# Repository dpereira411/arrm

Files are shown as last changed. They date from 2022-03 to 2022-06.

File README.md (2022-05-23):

# Active Real Ring Modulator

This is a Kosmo format synth module based on Ken Stone's CGS [https://sdiy.info/wiki/CGS_active_real_ring_modulator](Active Real Ring Modulator). 

Main difference with Stone's original are:

* The instrument preamplifier was omitted
* Transformer footprints are for the TY-141P instead of the less available MO222
* Final stage input resistor is decreased to 10k, output resistor is increased to 1k, and a 100k pulldown is added on the output.

## Current draw
11.5 mA +12 V, 11.5 mA -12 V

## Photos

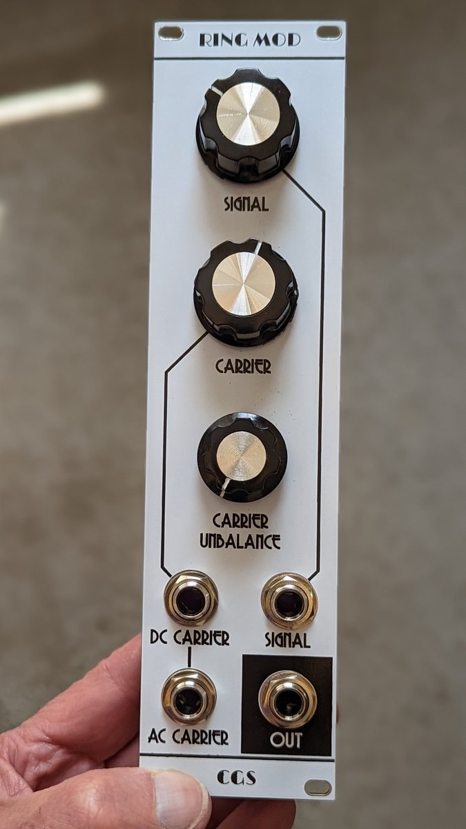
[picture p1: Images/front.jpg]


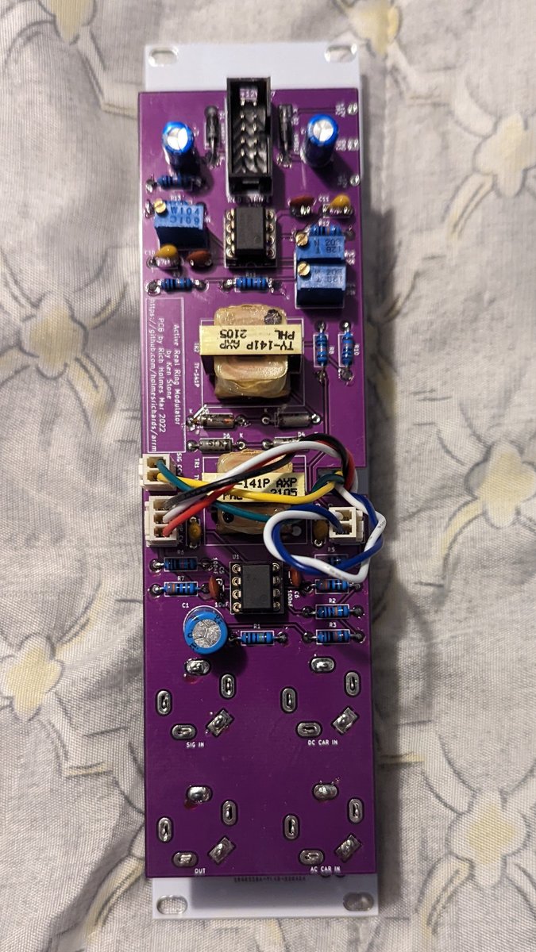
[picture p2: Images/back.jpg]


## Documentation

* [Schematic](Docs/arrm.pdf)
* PCB layout: [front](Docs/arrm_layout_front.pdf), [back](Docs/arrm_layout_back.pdf)
* [BOM](Docs/arrm_bom.md)
* [Build notes](Docs/build.md)
* [Blog post](https://analogoutputblog.wordpress.com/2022/05/05/cgs-ken-stone-active-real-ring-modulator/)

## GitHub repository

* [https://github.com/holmesrichards/arrm](https://github.com/holmesrichards/arrm)

## Submodules

This repo uses submodules aoKicad and Kosmo_panel, which provide needed libaries for KiCad. To clone:

```
git clone git@github.com:holmesrichards/arrm.git
git submodule init
git submodule update
```

Alternatively do

```
git clone --recurse-submodules git@github.com:holmesrichards/arrm.git
```

Or if you download the repository as a zip file, you must also click on the "aoKicad" and "Kosmo\_panel" links on the GitHub page (they'll have "@ something" after them) and download them as separate zip files which you can unzip into this repo's aoKicad and Kosmo\_panel directories.

If desired, copy the files from aoKicad and Kosmo\_panel to wherever you prefer (your KiCad user library directory, for instance, if you have one). Then in KiCad, go into Edit Symbols and add symbol libraries 

```
aoKicad/ao_symbols
Kosmo_panel/Kosmo
```
and go into Edit Footprints and add footprint libraries 
```
aoKicad/ao_tht
Kosmo_panel/Kosmo_panel.
```

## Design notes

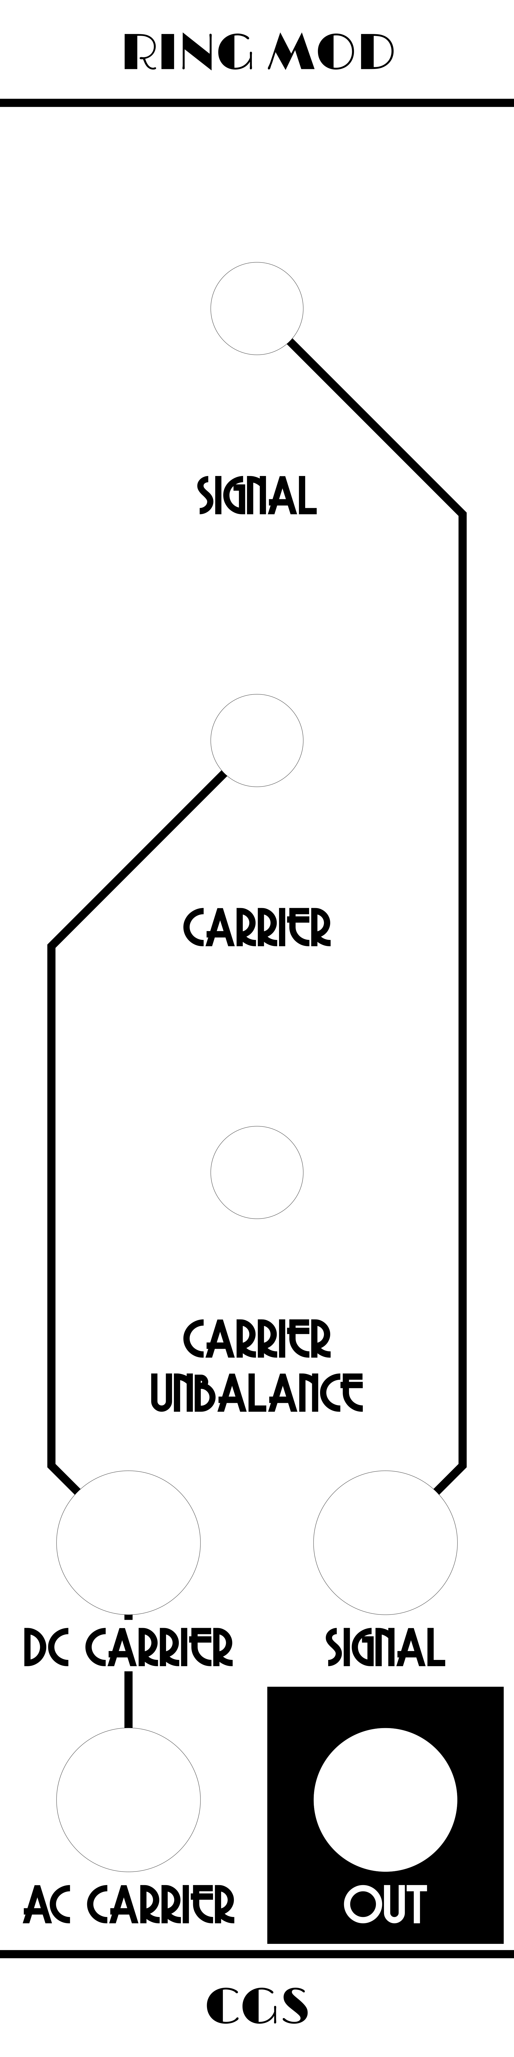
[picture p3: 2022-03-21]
Images/arrm_panel_art.png

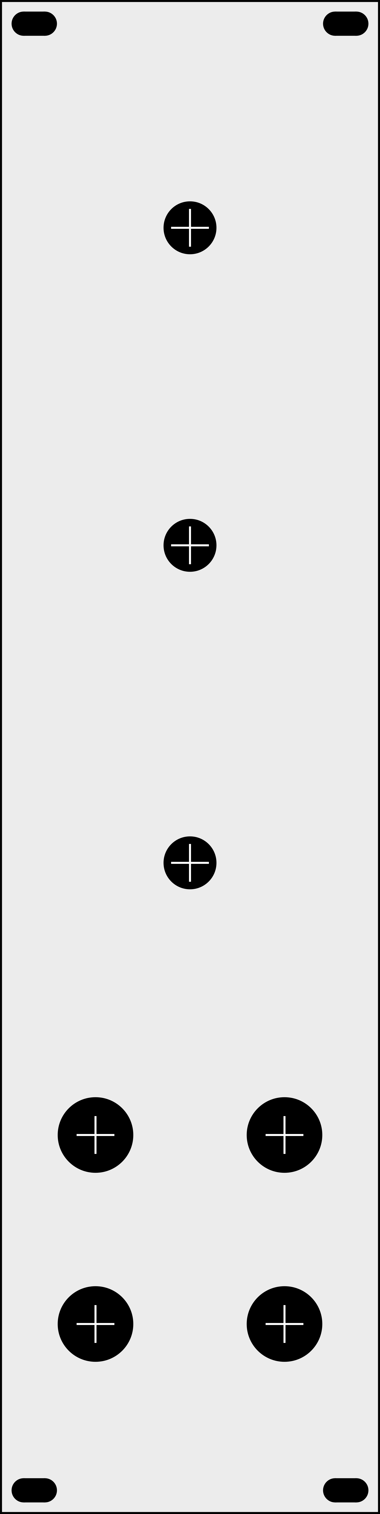
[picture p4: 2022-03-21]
Images/arrm_panel_holes.png

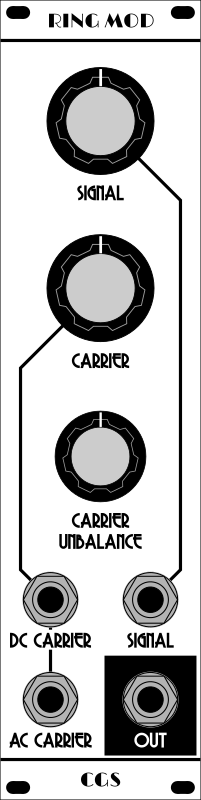
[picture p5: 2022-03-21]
Images/arrm_panel.png

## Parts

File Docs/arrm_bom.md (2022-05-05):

# arrm.kicad_sch BOM

Thu 05 May 2022 06:47:17 PM EDT

Generated from schematic by Eeschema 6.0.4-6f826c9f35~116~ubuntu20.04.1

**Component Count:** 52

| Refs | Qty | Component | Description | Vendor | SKU |
| ----- | --- | ---- | --- | ---- | ---- |
| C1 | 1 | 10uF | Non polarized electrolytic capacitor, pitch 3.5 mm | Tayda | A-4216 |
| C2, C7, C10, C11 | 4 | 47pF | Ceramic capacitor, pitch 5 mm | Tayda |  |
| C3, C4 | 2 | 10uF | Electrolytic capacitor, pitch 2.5 mm | Tayda | A-4349 |
| C5, C6, C8, C9 | 4 | 100nF | Ceramic capacitor, pitch 2.5 mm | Tayda | A-553 |
| D1, D2 | 2 | 1N5817 | Schottky Barrier Rectifier Diode, DO-41 | Tayda | A-159 |
| D3, D4, D5, D6 | 4 | 1N695 | Germanium diode, DO-35 |  |  |
| J1 | 1 | 3_pin_Molex_header | KK254 Molex header | Tayda | A-805 |
| J2, J3 | 2 | 2_pin_Molex_header | KK254 Molex header | Tayda | A-804 |
| J4 | 1 | 3_pin_Molex_connector | KK254 Molex connector | Tayda | A-827 |
| J5, J6 | 2 | 2_pin_Molex_connector | KK254 Molex connector | Tayda | A-826 |
| J7 | 1 | Synth_power_2x5 | Pin header 2.54 mm 2x5 | Tayda | A-2939 |
| J8, J9, J10, J11 | 4 | AudioJack2 | 1/4" audio jack, vertical | Tayda | A-1121 |
| R1 | 1 | 1M | Resistor, 1/4 watt metal film | Tayda |  |
| R2, R3, R6, R8, R9, R10, R12, R14 | 8 | 100k | Resistor, 1/4 watt metal film | Tayda |  |
| R4 | 1 | 330k | Resistor, 1/4 watt metal film | Tayda |  |
| R5, R7 | 2 | 330R | Resistor, 1/4 watt metal film | Tayda |  |
| R11 | 1 | 10k | Resistor, 1/4 watt metal film | Tayda |  |
| R13 | 1 | 1k | Resistor, 1/4 watt metal film | Tayda |  |
| RV1, RV2, RV3 | 3 | 100k | Linear potentiometer, panel mount | Tayda | A-1984 |
| RV4, RV5 | 2 | 20k | Trim-potentiometer | Tayda | A-592 |
| RV6 | 1 | 100k | Trim-potentiometer | Tayda | A-587 |
| TR1, TR2 | 2 | TY-141P | 0.3-300MHz 1:1 RF Transformer, Unbalanced to Balanced Center Tap at Primary/Secondary, CD542 |  |  |
| U1 | 1 | NE5532 | Dual Low-Noise Operational Amplifiers, DIP-8/SOIC-8 | Tayda | A-031 |
| U2 | 1 | TL072 | Dual operational amplifier, DIP-8 | Tayda | A-037 |
| | 2 | | 8 pin DIP socket | Tayda | A-001 |

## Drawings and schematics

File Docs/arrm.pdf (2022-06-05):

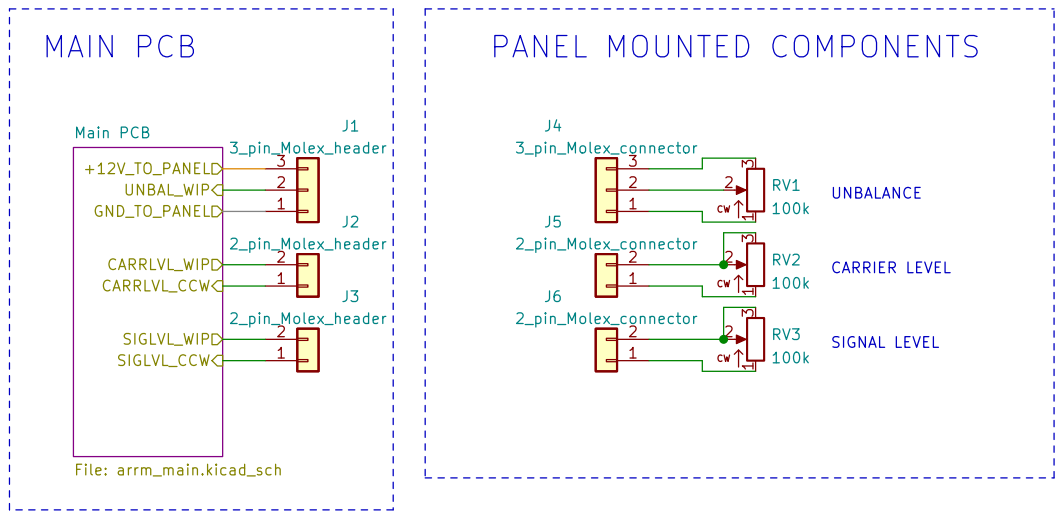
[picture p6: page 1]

SIGNAL LEVEL PANEL MOUNTED COMPONENTS

Circuit design by Ken Stone. SIGLVL_CCW

To the extent possible under law, Richard Holmes has waived all copyright and related
or neighboring rights to this work. Published from United States.
File: arrm.kicad_sch Sheet: / Rich Holmes / Analog Output

Id: 1/2 Title: Active Real Ring Modulator

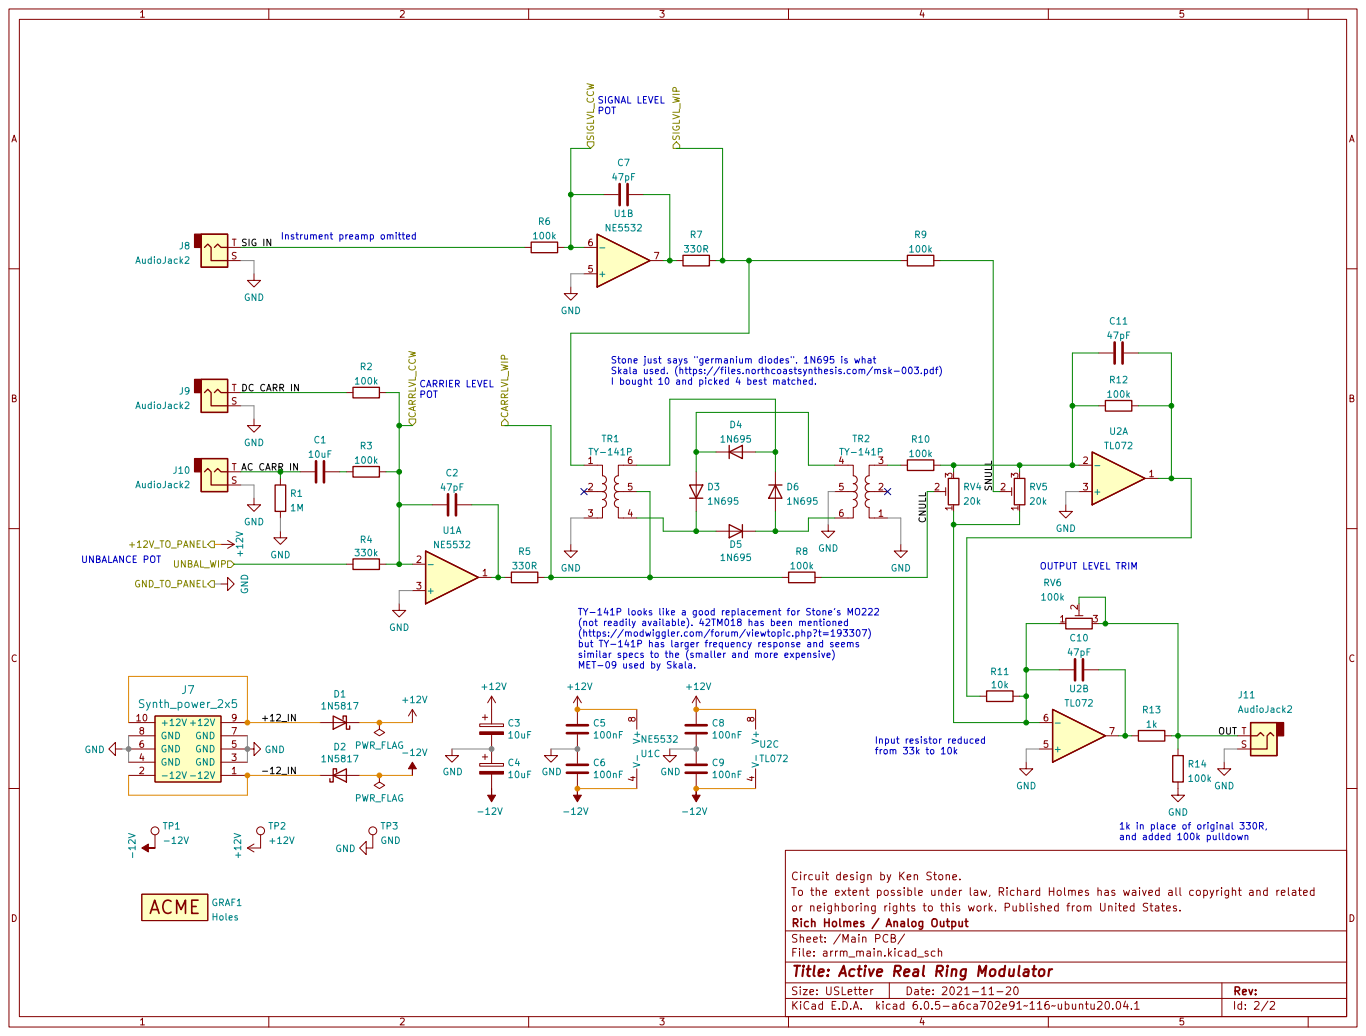
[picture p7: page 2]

I bought 10 and picked 4 best matched. SIGNAL LEVEL POT

Instrument preamp omitted UNBALANCE POT

Stone just says "germanium diodes". 1N695 is what
Skala used. (https://files.northcoastsynthesis.com/msk-003.pdf)

MET-09 used by Skala. CARRIER LEVEL POT

and added 100k pulldown OUTPUT LEVEL TRIM

from 33k to 10k TY-141P looks like a good replacement for Stone's MO222
(not readily available). 42TM018 has been mentioned
(https://modwiggler.com/forum/viewtopic.php?t=193307)
but TY-141P has larger frequency response and seems
similar specs to the (smaller and more expensive)

1k in place of original 330R,

Circuit design by Ken Stone.
To the extent possible under law, Richard Holmes has waived all copyright and related
or neighboring rights to this work. Published from United States.
File: arrm_main.kicad_sch Sheet: /Main PCB/ Rich Holmes / Analog Output

Id: 2/2 Title: Active Real Ring Modulator

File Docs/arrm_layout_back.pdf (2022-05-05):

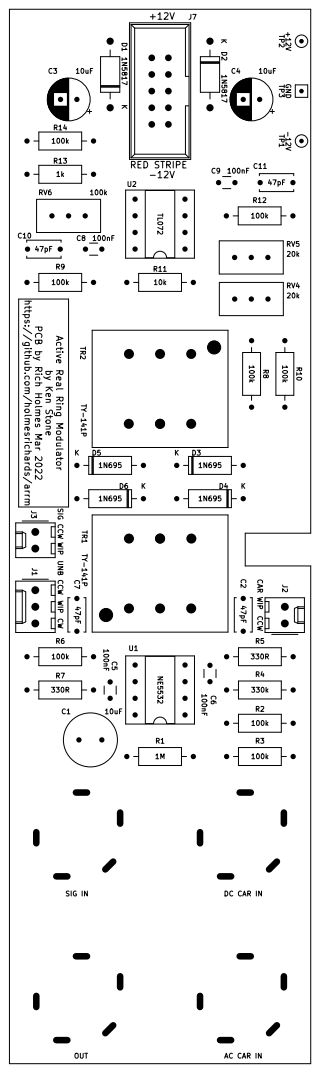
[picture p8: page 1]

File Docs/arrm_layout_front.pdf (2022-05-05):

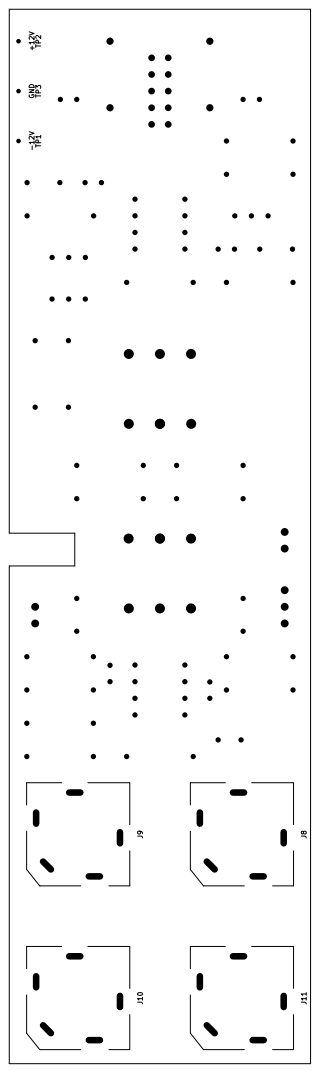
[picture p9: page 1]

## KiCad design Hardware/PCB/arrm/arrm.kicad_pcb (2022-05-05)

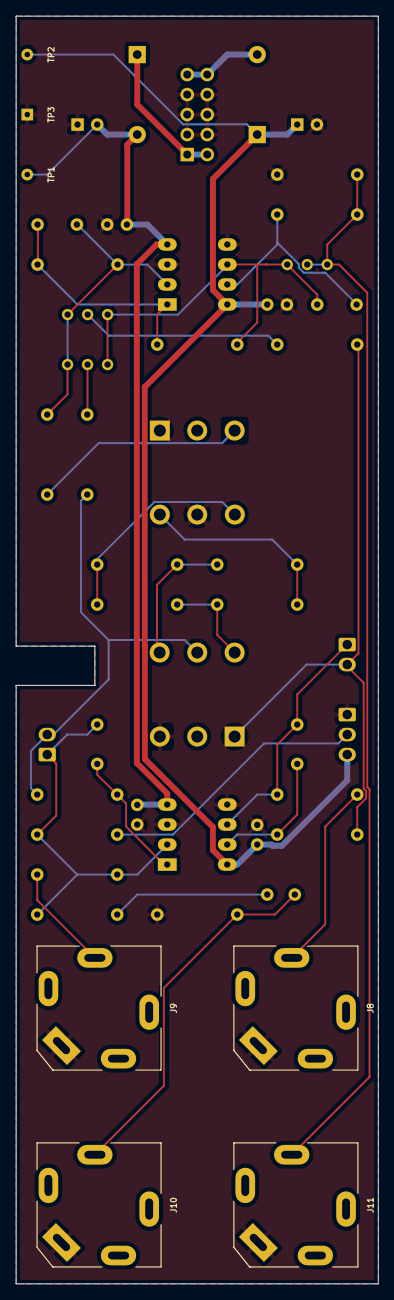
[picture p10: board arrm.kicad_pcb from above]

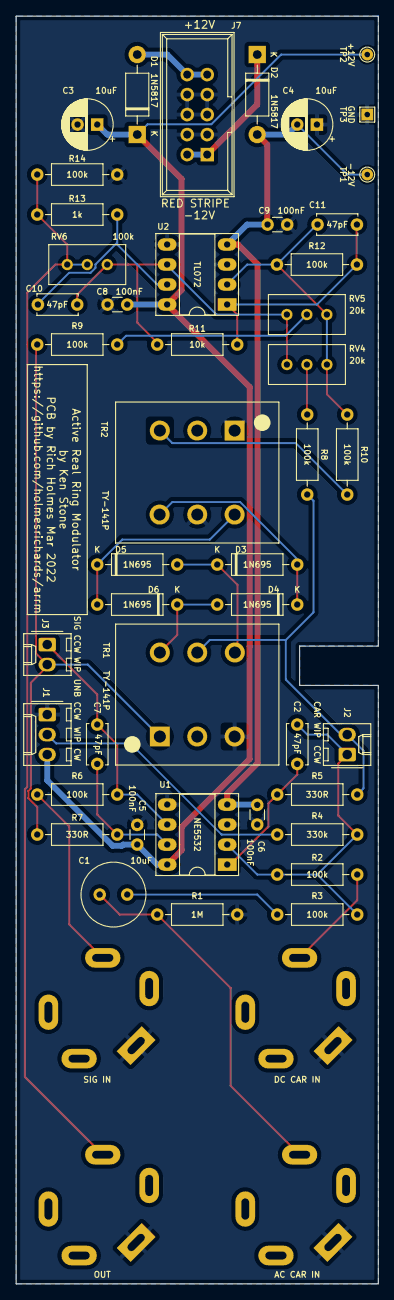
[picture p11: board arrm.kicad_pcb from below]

Board: 2 copper layers, 46.0 x 161.0 mm, 50 parts (45 on the bottom side), 28 nets.

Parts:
C1: 10uF; C_Radial_D8.0mm_H11.5mm_P3.50mm
C2, C7, C10, C11: 47pF; C_Disc_D5.0mm_W2.5mm_P5.00mm
C3, C4: 10uF; CP_Radial_D6.3mm_P2.50mm
C5, C6, C8, C9: 100nF; C_Disc_D3.0mm_W1.6mm_P2.50mm
D1, D2: 1N5817; D_DO-41_SOD81_P10.16mm_Horizontal
D3, D4, D5, D6: 1N695; D_DO-7_P10.16mm_Horizontal
GRAF1: Holes; ringmod_panel_2_holes
J1: 3_pin_Molex_header; Molex_KK-254_AE-6410-03A_1x03_P2.54mm_Vertical
J2, J3: 2_pin_Molex_header; Molex_KK-254_AE-6410-02A_1x02_P2.54mm_Vertical
J7: Synth_power_2x5; Power_Header
J8, J9, J10, J11: AudioJack2; Jack_6.35mm_PJ_629HAN_slots
R1: 1M; R_Axial_DIN0207_L6.3mm_D2.5mm_P10.16mm_Horizontal
R2, R3, R6, R8, R9, R10, R12, R14: 100k; R_Axial_DIN0207_L6.3mm_D2.5mm_P10.16mm_Horizontal
R4: 330k; R_Axial_DIN0207_L6.3mm_D2.5mm_P10.16mm_Horizontal
R5, R7: 330R; R_Axial_DIN0207_L6.3mm_D2.5mm_P10.16mm_Horizontal
R11: 10k; R_Axial_DIN0207_L6.3mm_D2.5mm_P10.16mm_Horizontal
R13: 1k; R_Axial_DIN0207_L6.3mm_D2.5mm_P10.16mm_Horizontal
RV4, RV5: 20k; Potentiometer_Bourns_3296W_Vertical_standard
RV6: 100k; Potentiometer_Bourns_3296W_Vertical_standard
TP1: -12V; TestPoint_THTPad_D1.5mm_Drill0.7mm
TP2: +12V; TestPoint_THTPad_D1.5mm_Drill0.7mm
TP3: GND; TestPoint_THTPad_1.5x1.5mm_Drill0.7mm
TR1, TR2: TY-141P; Transformer_TY-141P
U1: NE5532; DIP-8_W7.62mm_Socket_LongPads
U2: TL072; DIP-8_W7.62mm_Socket_LongPads

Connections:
+12V: C3.1, C5.1, C8.1, D1.1 (K), J1.3, TP2.1, U1.8 (V+), U2.8 (V+)
-12V: C4.2, C6.2, C9.2, D2.2 (A), TP1.1, U1.4 (V-), U2.4 (V-)
/Main PCB/+12_IN: D1.2 (A), J7.9 (+12V), J7.10 (+12V)
/Main PCB/-12_IN: D2.1 (K), J7.1 (-12V), J7.2 (-12V)
/Main PCB/AC CARR IN: C1.2, J10.T, R1.1
/Main PCB/CARRLVL_CCW: C2.1, J2.1, R2.2, R3.2, R4.2, U1.2 (-)
/Main PCB/CARRLVL_WIP: J2.2, R5.2, R8.1, TR1.5
/Main PCB/CNULL: R8.2, RV4.2
/Main PCB/DC CARR IN: J9.T, R2.1
/Main PCB/OUT: J11.T, R13.2, R14.2, RV6.2, RV6.3
/Main PCB/SIG IN: J8.T, R6.1
/Main PCB/SIGLVL_CCW: C7.1, J3.1, R6.2, U1.6 (-)
/Main PCB/SIGLVL_WIP: J3.2, R7.2, R9.1, TR1.1
/Main PCB/SNULL: R9.2, RV5.2
/Main PCB/UNBAL_WIP: J1.2, R4.1
GND: C3.2, C4.1, C5.2, C6.1, C8.2, C9.1, J1.1, J7.3 (GND), J7.4 (GND), J7.5 (GND), J7.6 (GND), J7.7 (GND), J7.8 (GND), J8.S, J9.S, J10.S, J11.S, R1.2, R14.1, TP3.1, TR1.3, TR2.1, TR2.5, U1.3 (+), U1.5 (+), U2.3 (+), U2.5 (+)
unnamed: C1.1, R3.1
unnamed: C2.2, R5.1, U1.1
unnamed: C7.2, R7.1, U1.7
unnamed: C10.1, R11.2, RV4.1, RV5.1, RV6.1, U2.6 (-)
unnamed: C10.2, R13.1, U2.7
unnamed: C11.1, R10.2, R12.1, RV4.3, RV5.3, U2.2 (-)
unnamed: C11.2, R11.1, R12.2, U2.1
unnamed: D3.1 (K), D5.2 (A), TR1.4
unnamed: D3.2 (A), D4.1 (K), TR2.4
unnamed: D4.2 (A), D6.1 (K), TR1.6
unnamed: D5.1 (K), D6.2 (A), TR2.6
unnamed: R10.1, TR2.3

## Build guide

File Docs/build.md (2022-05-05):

# Active Real Ring Modulator build notes

## Erratum

On the first PCB run, the transformer footprints are incorrect; mainly the problem is the dots indicating pin 1 are in the wrong place. They should look like this:

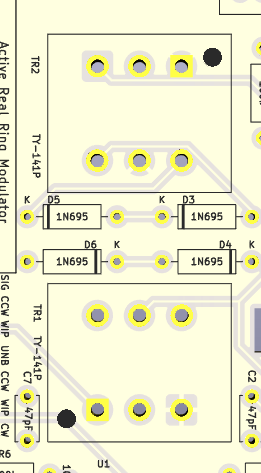
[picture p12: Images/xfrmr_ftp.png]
xfrmr_ftp


Place the dot side of the transformer toward the bottom for TR1 and toward the top for TR2.

R4 has the wrong value shown on the first run PCB silkscreen; it should be 330k, not 330R.

These were corrected after the first run.

# Build

There's nothing exotic about this build. Proceed as usual. Be careful not to overheat the germanium diodes.

Pins 2 and 3 (wiper and clockwise pins as viewed from front) of the Signal and Carrier pots should be connected together, and pins 1 and 2 should be wired to the PCB via Molex connectors or soldered directly. All three pins of the Carrier Unbalance pot should be wired to the PCB. See labels on the PCB indicating which pin goes to which point.

# Diodes

I used the rather traditional 1N695 germanium diodes but you can substitute other diodes. Regular silicon junction diodes like 1N4148 can be used although their high forward voltage means there will be more distortion. Schottky diodes like 1N5817 will have even lower forward voltage than most germanium and a steeper I vs V curve, which may give you results you'd prefer. 

Germanium diodes tend to be more variable, so if your multimeter has a diode setting, use it to select four diodes with closely matched forward voltage.

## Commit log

2021-11-24 Initial version
    [ringmod.kicad_pcb, ringmod.kicad_sch, ringmod_2.kicad_pcb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]
2021-11-25 Update pot symbols
    [ringmod_2.kicad_sch, ringmod_main.kicad_sch]
2021-12-11 .gitignore, fix pot symbols
    [ringmod_2.kicad_sch, ringmod_main.kicad_sch]
2021-12-22 remove inst preamp, redesign panel
    [ringmod_2.kicad_pcb, ringmod_2.kicad_sch, ringmod_main.kicad_sch]
2022-02-01 rm first design; add new holes image
    [ringmod.kicad_pcb, ringmod.kicad_sch, ringmod_2.kicad_pcb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]
2022-03-12 Layout revision
    [ringmod_2.kicad_pcb]
2022-03-19 Rename project; reduce input resistor on output stage
    [arrm.kicad_pcb, arrm.kicad_sch, arrm_main.kicad_sch]
2022-03-21 Rename project, cleanup
    [arrm.kicad_pcb, arrm.kicad_sch, arrm_main.kicad_sch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]
2022-05-03 Final pre fab tweaks, Gerbers
    [arrm-CmtUser.gbr, arrm-CuBottom.gbl, arrm-CuTop.gtl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]
2022-05-03 Fix footprint path; fix transformer footprint
    [arrm.kicad_pcb, arrm.kicad_sch, arrm_main.kicad_sch]
2022-05-05 Post fab updates
    [arrm.kicad_sch, arrm_main.kicad_sch]
2022-05-05 Docs, pics, new Gerbers
    [arrm-CmtUser.gbr, arrm-CuBottom.gbl, arrm-CuTop.gtl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]
2022-05-05 R4 should be 330k
    [arrm.kicad_pcb, arrm.kicad_sch, arrm_main.kicad_sch]
2022-05-23 Current draw
2022-06-05 Also fix schematic R4
